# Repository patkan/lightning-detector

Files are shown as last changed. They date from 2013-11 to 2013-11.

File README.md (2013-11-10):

lightning-detector
==================

Lightning Detector ethernet sensor node and server based on AS3935 and ATmega328

by Virtex7 and patkan

<h3>Structure</h3>

server: Server-Software
    
pcb: KiCAD-Schematic and Layout

code: Code for the node

<h3>Aim</h3>

The aim of this project is to develop a network of sensors.
Those mainly detect lightning events, their intensity and distance.
As an addition the sensor nodes might capture weather data (light level, humidity, temperature, maybe pressure).

The captured data is then transferred to a single server together with a timestamp and the position of the node.
This server tries to determine the exact position of the lightning events by triangulation.
In further steps the server could generate maps and lists of lightning events.

The captured data shall be accessible to everyone without registration.
New sensors should be able to "join" the network by simply sending data to the server.
The server will provide the raw sensor data and the correlated values.
The complete project code (including microcontroller firmware and aggregation server) and board layout will be distributed under an open source license.

This project tries to be different from blitzortung.org. The code and layout shall be easily accesible.
The captured data shall be accessible for everyone (even if the user is not providing sensor data).
The hardware necessary for the absolute basic setup should not cost more than 25€ - 30€.
Everyone is free to use the data commercially, if desired.
However, it should be noted that no one can be taken liable for the correctness of the captured data.

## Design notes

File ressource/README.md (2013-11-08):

MATERIAL
==================
This directory contains material like app notes and datasheets that are not part of the open source project. They are excluded from the licensing of the project.

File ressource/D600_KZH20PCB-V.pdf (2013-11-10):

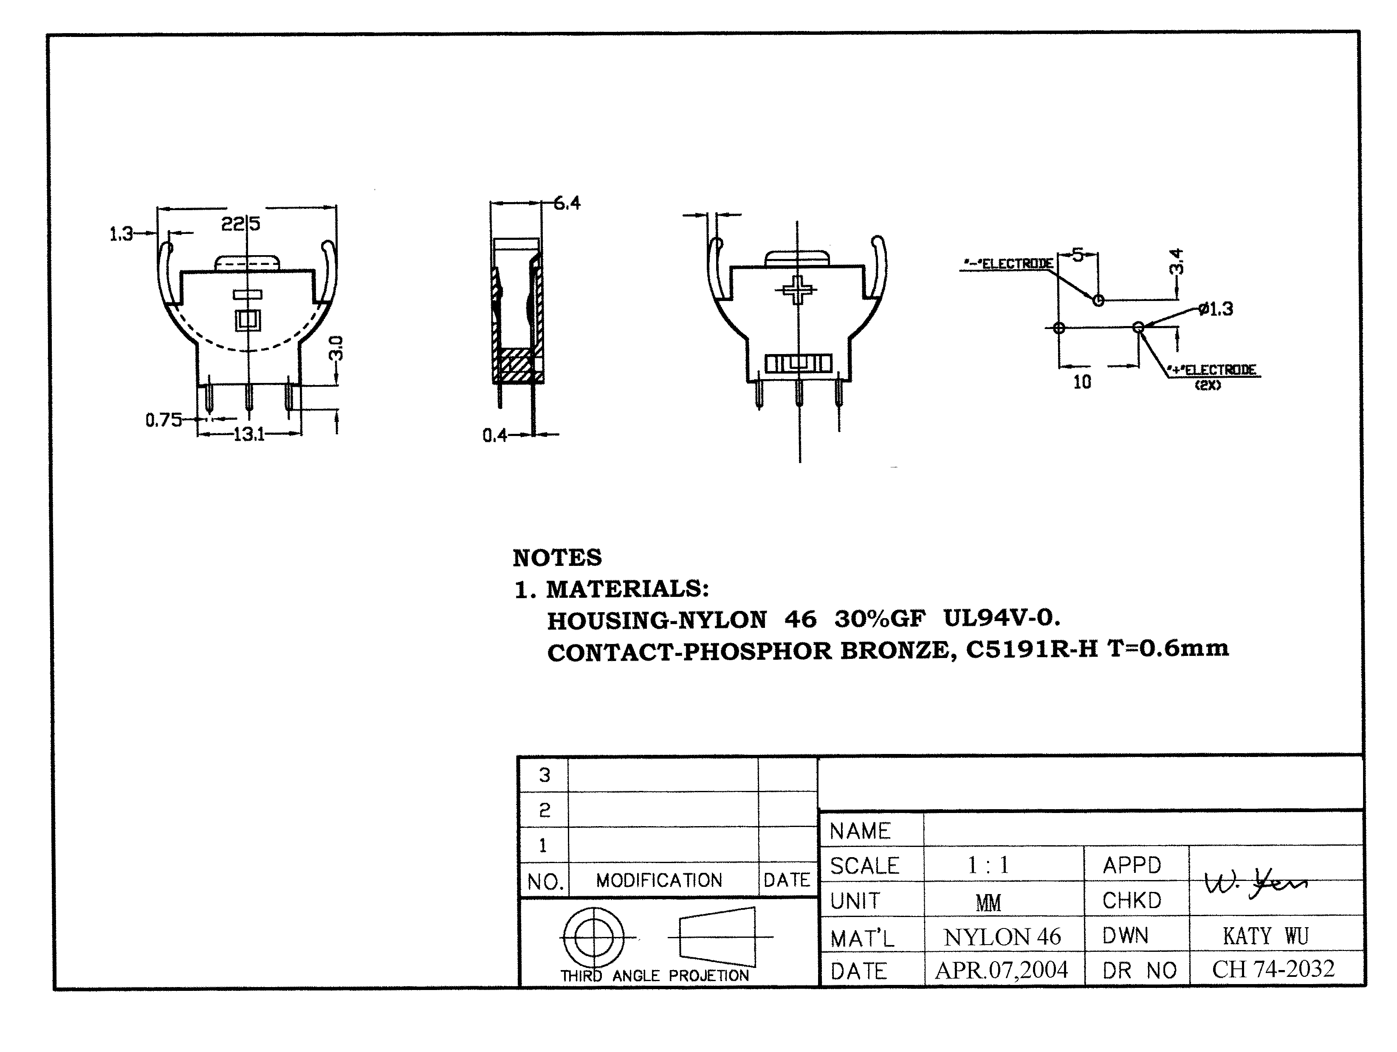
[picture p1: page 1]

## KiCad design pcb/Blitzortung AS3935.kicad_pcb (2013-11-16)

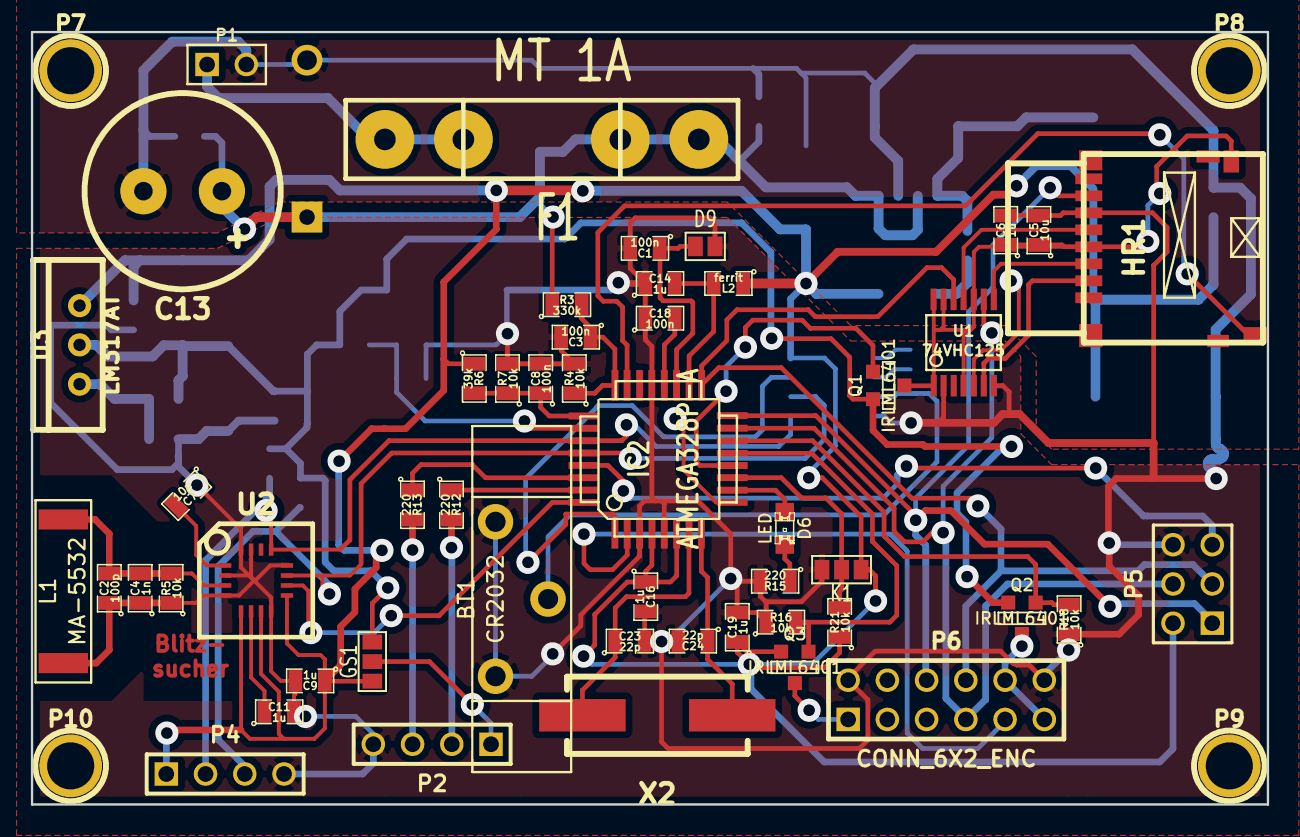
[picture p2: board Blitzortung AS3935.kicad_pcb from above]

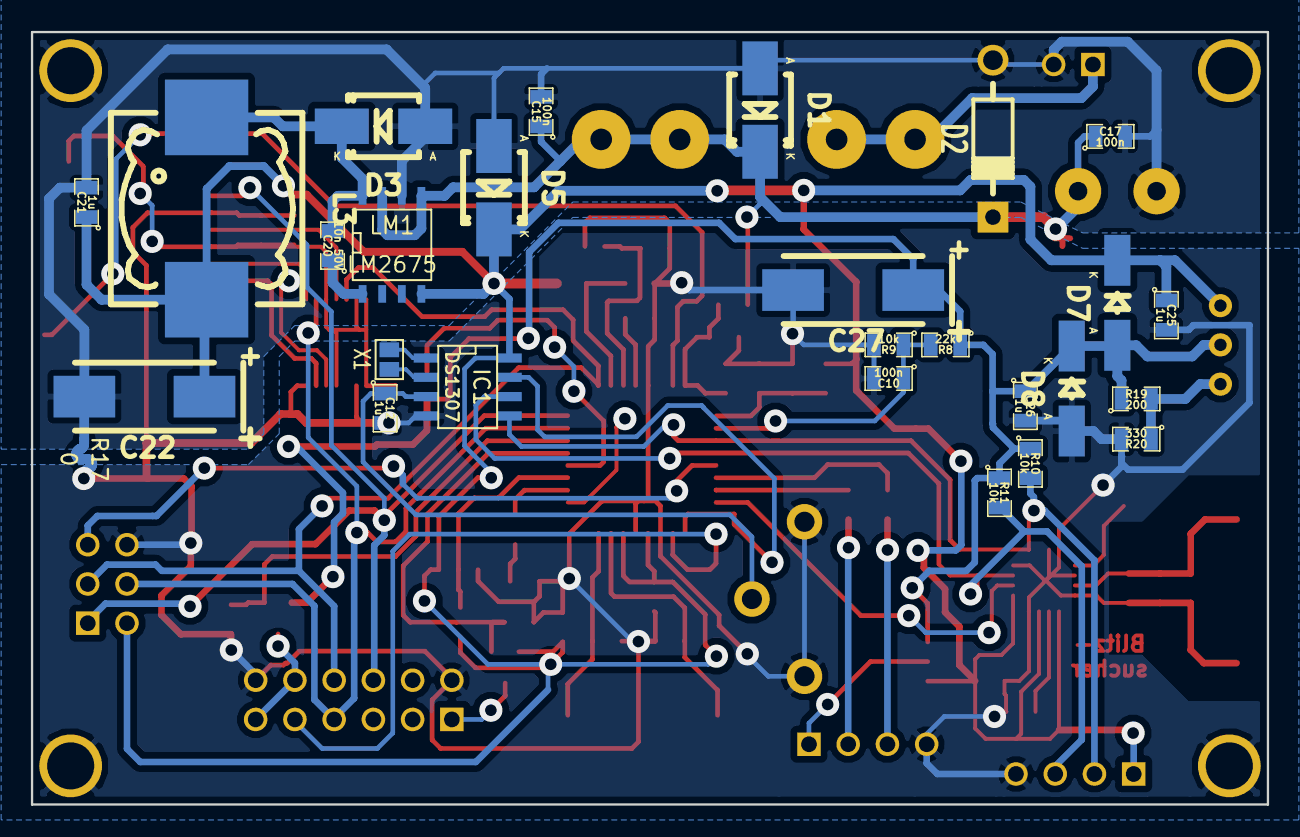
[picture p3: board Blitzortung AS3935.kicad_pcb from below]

Board: 2 copper layers, 80.0 x 50.0 mm, 81 parts (27 on the bottom side), 51 nets.

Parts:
BT1: CR2032; KHZ 20PCB-V
C1, C3, C8, C10, C15, C17, C18: 100n; SM0805
C2: 100p; SM0805
C4: 1n; SM0805
C5, C7: 10u; SM0805
C6, C9, C11, C12, C14, C16, C19, C21, C25, C26: 1u; SM0805
C13: 470u; Elko_vert_DM12-5_RM5
C20: 10n 50V; SM0805
C22, C27: 47u Tantal; TantalC_SizeD_EIA-7343_HandSoldering_RevA_28Aug2012
C23, C24: 22p; SM0805
D1: p6ke39aSMD; Diode-SMB_Handsoldering_RevA_27July2010
D2: SB150; Diode_DO-41_SOD81_Horizontal_RM10
D3: PMEG6030; Diode-SMB_Handsoldering_RevA_27July2010
D5: p6ke6,8aSMD; Diode-SMB_Handsoldering_RevA_27July2010
D6: LED; LED-0805
D7: 1n4148; Diode-MiniMELF_Handsoldering_RevA_27July2010
D8: zf3,6SMD; Diode-MiniMELF_Handsoldering_RevA_27July2010
D9: BPW34; GS2
F1: MT 1A; FUSE5-20
GS1: GS3
HR1: DM3D-SF
IC1: DS1307; SOIC-8_N
IC2: ATMEGA328P-A; TQFP32
K1: CONN_3_DHT; GS3
L1: MA-5532; MA5532-AE
L2: ferrit; SM0805
L3: 68uH; Choke_SMD_Wuerth-WE-PD-Typ-LS_Handsoldering_RevA_27July2010
LM1: LM2675; SO8N
P1: CONN_2_pwr; PIN_ARRAY_2X1
P2: CONN_4_GPS; PIN_ARRAY_4x1
P4: CONN_4_I2C; PIN_ARRAY_4x1
P5: CONN_3X2_ISP; pin_array_3x2
P6: CONN_6X2_ENC; pin_array_6x2
P7, P8, P9, P10: CONN_1; 1pin
Q1, Q2, Q3: IRLML6401; SOT23GDS
R3: 330k; SM0805
R4, R5, R7, R9, R10, R11, R16, R18, R21: 10k; SM0805
R6: 39k; SM0805
R8: 22k; SM0805
R12, R13, R15: 220; SM0805
R17: 0; MuSelf
R19: 200; SM0805
R20: 330; SM0805
U1: 74VHC125; SSOP-14
U2: AS3935; QFN-16-P
U3: LM317AT; TO220_VERT_123
X1: Uhrenquarz; GS2
X2: 20MHz; Crystal_HC49-SD_SMD_RevA_09Aug2010

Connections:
+3.3V: C26.1, C27.1, D7.1, D8.2, GS1.3, Q1.S, Q2.S, R8.1, R10.1, R11.1, R19.1, U3.2
+5V: C9.1, C16.1, C19.1, C21.1, C22.1, C25.1, D5.2, D7.2, GS1.1, IC1.8, IC2.4, IC2.6, K1.1, L2.1, L3.2, LM1.4, P4.1, P5.2, Q3.S, R6.1, R21.1, U2.5, U2.7, U2.9, U3.3
/IRQ_AS: IC2.32, U2.10
/IRQ_RTC: IC1.7, IC2.1
/IRQ_SD: HR1.10, IC2.23
/Vldr: C1.1, D9.1, IC2.19
/clk: HR1.5, U1.11
/cs: HR1.2, U1.6
/dht: IC2.11, K1.2, R21.2
/di: HR1.3, U1.8
/eth_3V: IC2.14, Q2.G, R18.2
/eth_5V: IC2.13, Q3.G, R16.2
/eth_cs: IC2.2, P6.9
/eth_res: P6.10, P6.11, Q2.D
/eth_sck: IC2.17, P5.3, P6.8, U1.12
/eth_si: IC2.15, P5.4, P6.7, U1.9
/eth_so: HR1.7, IC2.16, P5.1, P6.6
/mess3,3V: C10.1, IC2.26, R8.2, R9.1
/mess5V: C8.1, IC2.25, R6.2, R7.1
/messVin: C3.1, IC2.24, R3.2, R4.1
/reset: IC2.29, P5.5
/rxd: IC2.30, R13.1
/scl: IC1.6, IC2.28, P4.3, R11.2, U2.11
/sd3,3V: IC2.12, Q1.G
/sd_cs: IC2.9, U1.5
/sda: IC1.5, IC2.27, P4.2, R10.2, U2.13
/txd: IC2.31, R12.1
/xtal1: C23.1, IC2.7, X2.2
/xtal2: C24.1, IC2.8, X2.1
GND: BT1.2, C1.2, C2.1, C3.2, C4.1, C5.2, C6.2, C7.1, C8.2, C9.2, C10.2, C11.2, C12.2, C14.1, C16.2, C18.1, C19.2, C23.2, C24.2, C25.2, C26.2, C27.2, D8.1, D9.2, HR1.6, IC1.4, IC2.3, IC2.5, IC2.21, K1.3, L1.2, P2.4, P4.4, P5.6, P6.2, P6.12, P9.1, P10.1, R4.2, R5.1, R7.2, R9.2, R15.2, R16.1, R17.1, R18.1, R20.2, U1.2, U1.7, U2.2, U2.4, U2.8, U2.12, U2.15, U2.16
GNDPWR: C13.2, C15.2, C17.2, C21.2, C22.2, D1.1, D2.1, D3.1, D5.1, LM1.6, P1.2, P7.1, P8.1, R17.2
unnamed: BT1.1, C12.1, IC1.3
unnamed: C2.2, C4.2, L1.1, R5.2, U2.3
unnamed: C7.2, U2.1
unnamed: C11.1, U2.6
unnamed: C13.1, C15.1, C17.1, D1.2, D2.2, F1.2, LM1.5, LM1.7, R3.1
unnamed: C14.2, IC2.18, L2.2
unnamed: C18.2, IC2.20
unnamed: C20.1, LM1.1
unnamed: C20.2, D3.2, L3.1, LM1.8
unnamed: D6.1, IC2.10
unnamed: D6.2, R15.1
unnamed: F1.1, P1.1
unnamed: GS1.2, P2.1
unnamed: IC1.1, X1.2
unnamed: IC1.2, X1.1
unnamed: P2.2, R12.2
unnamed: P2.3, R13.2
unnamed: P6.1, Q3.D
unnamed: R19.2, R20.1, U3.1
VCC: C5.1, C6.1, HR1.4, HR1.9, Q1.D, U1.1, U1.4, U1.10, U1.13, U1.14

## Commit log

2013-11-08 new CAD Files for lightning-detector, in progress....
    [Blitzortung AS3935.sch]
2013-11-08 added Antenna
2013-11-08 AGC to ACG
    [Blitzortung AS3935.sch]
2013-11-08 ignoring .ps and .bak files from KiCAD
2013-11-08 datasheets of antenna and detector chip
2013-11-08 Update brainstorming.txt
    -Board sollte sich automatisch kofigurieren
    -Erzeugung eines eigenen Wetterfeeds anhand der Daten der eigenen Station
2013-11-08 new Ideas and more schematic - will be done soon...
    [Blitzortung AS3935.sch]
2013-11-08 new datasheet for the 5V switchmode converter and more schematic....
    [Blitzortung AS3935.sch]
2013-11-08 additional test leds and sensor connectors
    [Blitzortung AS3935.sch]
2013-11-09 some changes.....
    [Blitzortung AS3935.sch]
2013-11-09 selected inductors and diodes...
    [Blitzortung AS3935.sch]
2013-11-09 LDR-Messschaltung hinzugefügt
    [Blitzortung AS3935.sch]
2013-11-09 Beschriftung des LDR
    [Blitzortung AS3935.sch]
2013-11-09 LDR-Spannungsteiler aktualisiert
    [Blitzortung AS3935.sch]
2013-11-09 added one sick capacitor :D
    [Blitzortung AS3935.sch]
2013-11-09 switching mosfets for the ENC28J60 for energy saving :D
    [Blitzortung AS3935.sch]
2013-11-09 minor label corrections
    [Blitzortung AS3935.sch]
2013-11-09 input, 5V and 3,3V voltage measurement added
    [Blitzortung AS3935.sch]
2013-11-09 datasheet for SD-Card slot
2013-11-10 added SD-Card, real time clock and some small things....
    [Blitzortung AS3935.sch]
2013-11-10 changed ground plane for the 3,3V LDO to standard ground
    [Blitzortung AS3935.sch]
2013-11-10 sd card signal converter added.
    [Blitzortung AS3935.sch]
2013-11-10 changed crystal from 16MHz to 20MHz because I can.
    [Blitzortung AS3935.sch]
2013-11-10 footprint for DM3d-SF -- needs to be revised and enhanced
2013-11-10 enhanced footprint
2013-11-10 new datasheets and changes in the .pro-file only missing footprint: the sd card slot!
    [Blitzortung AS3935.sch]
2013-11-10 new TO-220 socket for the lm317 voltage regulator
2013-11-10 footprints and libs for battery holder and sdcard now up to date and included in schematic
    [Blitzortung AS3935.sch]
2013-11-10 footprint for QFN.Quark
2013-11-10 first layoutfile (with no layout in it, but created...) and even more datasheets..
    [Blitzortung AS3935.kicad_pcb]
2013-11-10 changed LDR to photodiode in schematic
    [Blitzortung AS3935.sch]
2013-11-10 added the qfn16 lib from patkan and converted it to a .mod file.
    [Blitzortung AS3935.sch]
2013-11-16 first attempt of layout - many many VIAs but still home-made manufacturing possible. you have to connect the SC_CS wire with a bridge on a virtual third layer. no warranty....
    [Blitzortung AS3935.kicad_pcb, Blitzortung AS3935.sch]
2013-11-18 Update brainstorming.txt
    Messung des Erdmagnetfeldes?
